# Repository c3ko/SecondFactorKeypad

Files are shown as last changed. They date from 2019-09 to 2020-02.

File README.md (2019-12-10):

# Build Instructions for Second Factor Keypad

## Table of Contents
1. [Introduction](#introduction)
2. [Bill of Materials](#bill-of-materials)
3. [Arduino IDE Configuration](#arduino-ide-configuration)
4. [Soldering and Assembly](#soldering-and-assembly)
5. [Serial Connection](#serial-connection)
6. [Power Up](#power-up)
7. [Testing](#testing)

### Introduction
The 12-Button Matrix Keypad uses a matrix of switches to track which column and row a pressed button is in. The development platform used to read the column/row outputs and drive the state for the lights and buzzer is the Nucleo L432KC. It comes equipped with an onboard ST-LINK v2 and is Arduino IDE compatible.

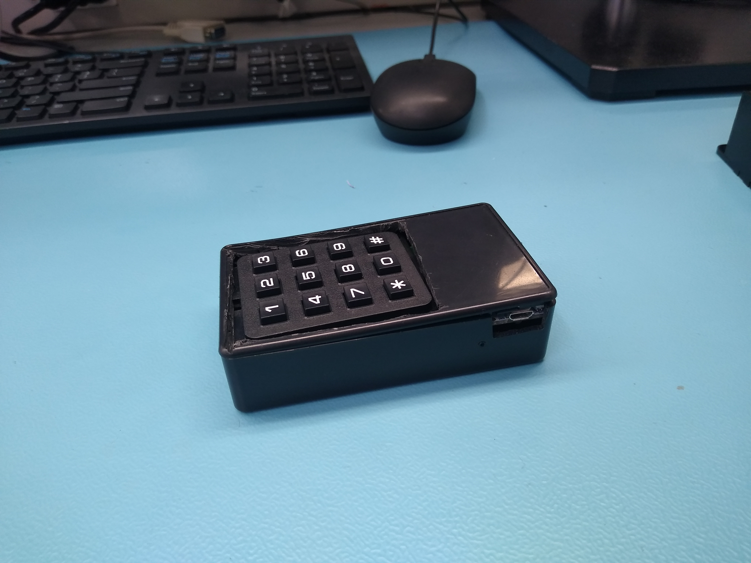
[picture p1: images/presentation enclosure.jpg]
Presentation enclosure


### Bill of Materials
(All Prices pre-tax and in CAD)

*  Nucleo L432KC STM32 Development Board - $15.176
*  COM-14662 12-Button Matrix Keypad - $6.87
*  Red LED - $0.86
*  Green LED - $0.83
*  Piezzo Speaker - $1.04

### Arduino IDE Configuration && installing Source Code
1) The Arduino IDE can be downloaded for free from https://www.arduino.cc/en/main/software and is available for Windows, Mac OS X and Linux.
2) Open Arduino IDE and click Files and then preference.
3) Add the stm32duino board manager repository by entering 'https://raw.githubusercontent.com/stm32duino/BoardManagerFiles/master/STM32/package_stm_index.json' in to 'Additional Boards Manager URLs' and click OK.
4) Plug the micro usb from the Nucleo in to the computer.
5) Click on Tools > Board > Boards Manager and install STM32 Core from the list.
6) Click Tools > Board and select Nucleo-32 and then click Tools > Board Part Number and select Nucleo L432KC.
6) Click Tool > Port and select the port the board is connected to.
7) Install the Keypad.h library by downloading keypad.zip from https://playground.arduino.cc/Code/Keypad/ and install it by clicking Sketch > Include Library > ADD .zip file and select keypad.zip file you downloaded.
7) Download/Copy the source code from https://github.com/c3ko/SecondFactorKeypad/blob/master/software/blink_example1.ino
8) Click Sketch > Upload and then Tools > Serial Monitor to see serial output. Make sure Tools > 
Upload Method is set to STM32CubeProgrammer(SWD).

### Soldering and Assembly
Use the following image as guide for correct position of board on to sockets:

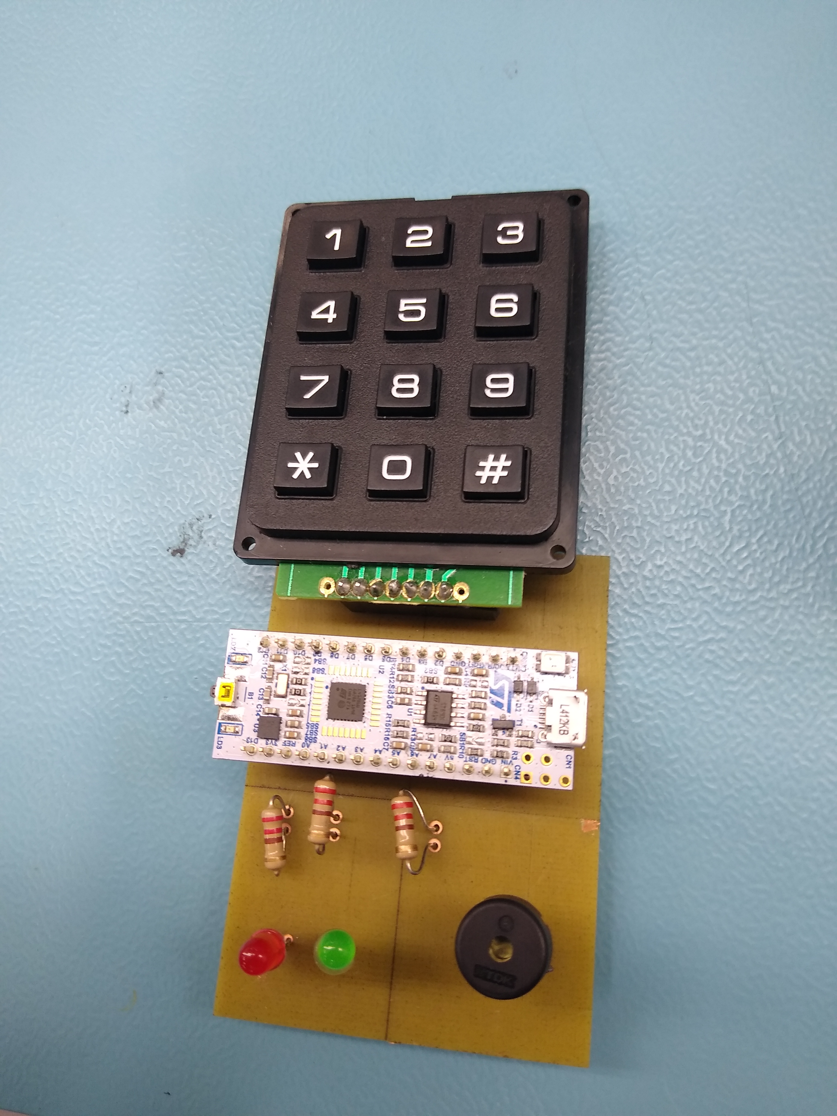
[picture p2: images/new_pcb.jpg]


The PCB Gerber files used for printing the board can be found at https://github.com/c3ko/SecondFactorKeypad/blob/master/mechanical/MohamedKore_SecondFactorKeypadV3.zip
##### Keypad Pins
* Solder Pins on to the Keypad.

#### PCB Pins

* Solder 7-pin single-line header socket on to board
* Solder 2 15-pin single line header sockets on to board
* Solder 3 330 ohm Resistors on to board at output pins for D10, D11, D12

* Solder Piezzo speaker and LED in to their positions based on pCB image above
<br/>

#### Enclosure
Enclosure can be produced using laser cutting of Acrylic. File for cutting can be found at:
https://github.com/c3ko/SecondFactorKeypad/blob/master/MohamedKoreBoxCase.cdr

Use a peice of styrofoam or hard plastic cut to 17mm height 53mm width, 53mm  length to be placed under cantilevered keypad as support.

### Power Up
When PCB hand connected components are inside the enclosure. Plug the Nucleo-32 in to computer using micro-USB outlet on side of enclosure.
### Testing

#### Unit Testing

After soldering the pins on to the keypad. Use a multimeter to measure resistance between the corresponding Row/Column pin for each button. The resistance should drop when button is pressed:

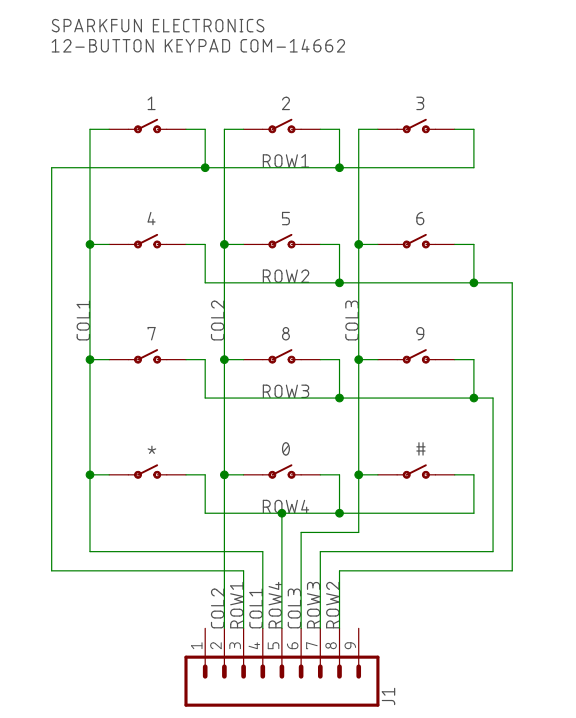
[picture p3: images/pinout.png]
keypad pinout


Test each of the LEDs and the piezzo speaker by setting their digital outputs in the Arduino IDE to high and uploading that sketch to the Nucleo-32.

#### Production Testing

### Reproducability
The project is easily reproducable as all of the components (resistors, keypad, led etc.) are well stocked at major electronic parts suppliers (Digi-key & Mouser). The development environment works on all major operating systems and all of the code has been provided.

### Reference

1.https://circuitdigest.com/microcontroller-projects/getting-started-with-stm32-development-board-stm32f103c8-using-arduino-ide

2. https://playground.arduino.cc/Code/Keypad/

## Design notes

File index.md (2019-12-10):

<h2> December 10, 2019 </h2>

<h3> Project Completion and Build Instructions </h3>

The presentation for this hardware project has been completed and the build instructions for replicating the device is in the README for the project.

<h2>December 3, 2019</h2>

<h3>Update</h3>

<p>
  
  Redesigned PCB to include LED lights and Piezzo speaker to indicate correct/incorrect pin.
  First 3D printing attempt at Idealab failed due to problems with filament. Vertical support on second 3D printed case was too high. Due to time restriction opted for a acrylic Case instead. This has added advantage of making LEDs easily visible withing creating holes for them in the case. Unfortunately didn't communicate need for clear acrylic case, will be sending for a clear top case this week. However, for the presentation I purchased an enclosure that fit my project from Amazon and milled holes using a Dremel handtool and circular saw.

Case used during presentation with old PCB:

Presentation enclosure

Updated PCB:

 Updated PCB
</p>

Failed 3D printed case:

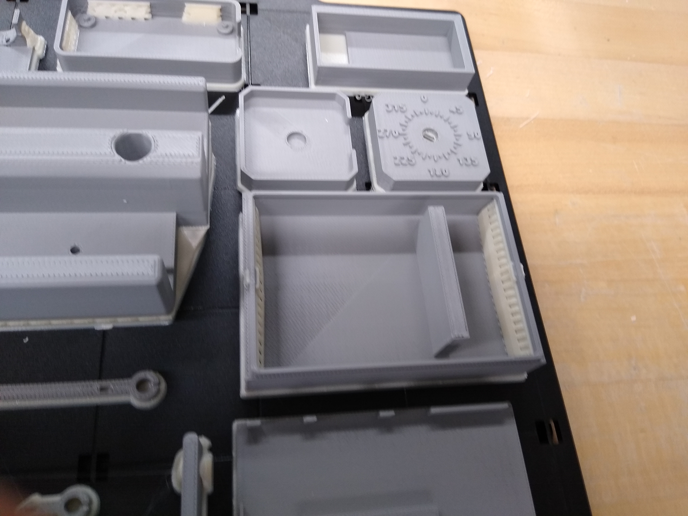
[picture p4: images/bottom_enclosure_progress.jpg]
3d case bottom


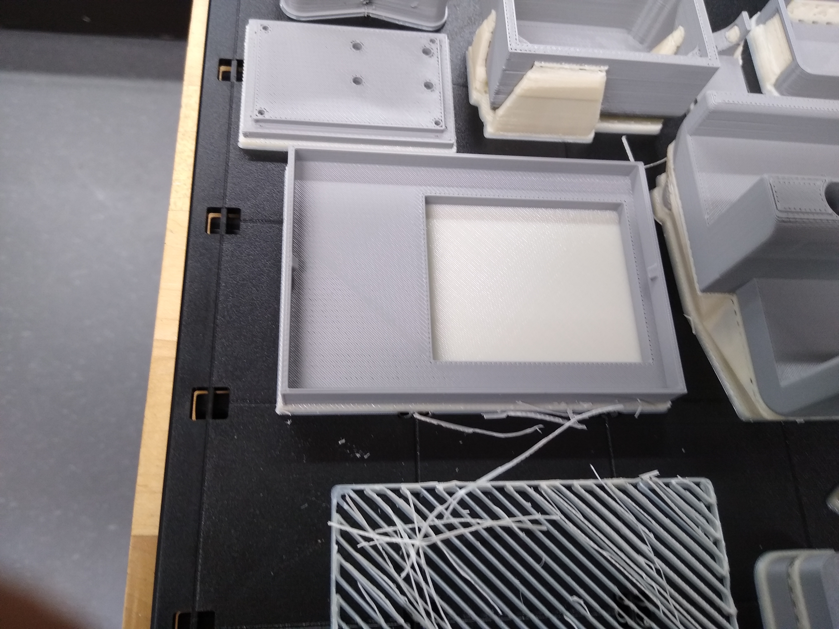
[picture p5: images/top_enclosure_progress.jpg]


<h2>November 26, 2019</h2>

<h3>Presentation Handed In</h3>

<p>
Presentation slides have been completed and can be found under the <a href="documentation/CENG317Presentation.pptx">documentation folder</a>
</p>

<h2>November 19, 2019</h2>

<h3>Enclosure Progress</h3>

<p>
The snap-fit enclosure case for the keypad will have a support cross-section for the keypad to rest on as its current cantilevered position will damage the sockets/pins when pressure is applied to the buttons.
</p>

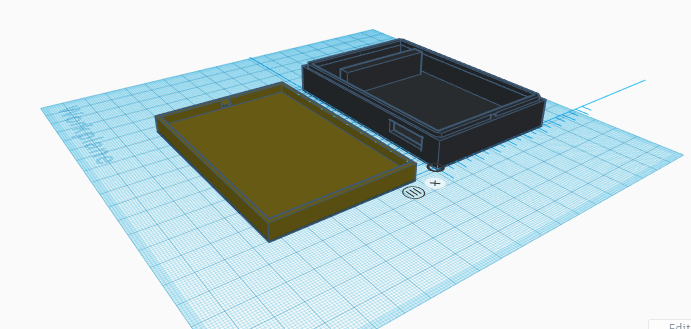
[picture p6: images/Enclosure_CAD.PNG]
keypad enclosure


The files can be found at:

<a href="mechanical/KeyPadEnclosure_bottom.stl">Bottom part of Enclosure STL</a>

<a href="mechanical/KeyPadEnclosure_top.stl">Top part of Enclosure STL</a>

Update: As of November 26, 2019. The enclosure has finished printing but is currently in solution to remove the support material. The tentative date for completion is November 27, 2019.

bottom enclosure progress picture
top enclosure progress picture

<h2>November 11, 2019</h2>

<h3>PCB Powered On</h3>
The 12-Button Keypad uses a grid with switches were connections are closed and a lower resistance allows 5V to pass through. This method for reading key presses doesn't require seperate pins for power and ground so powering up this PCB is as simple as plugging in the the input pins into the socket on the PCB connecting it to the inputs A0-A8 on the Nucleo-32.

keypad pinout

As the images below show. The PCB is powered on and is communicating key presses serially to a terminal:
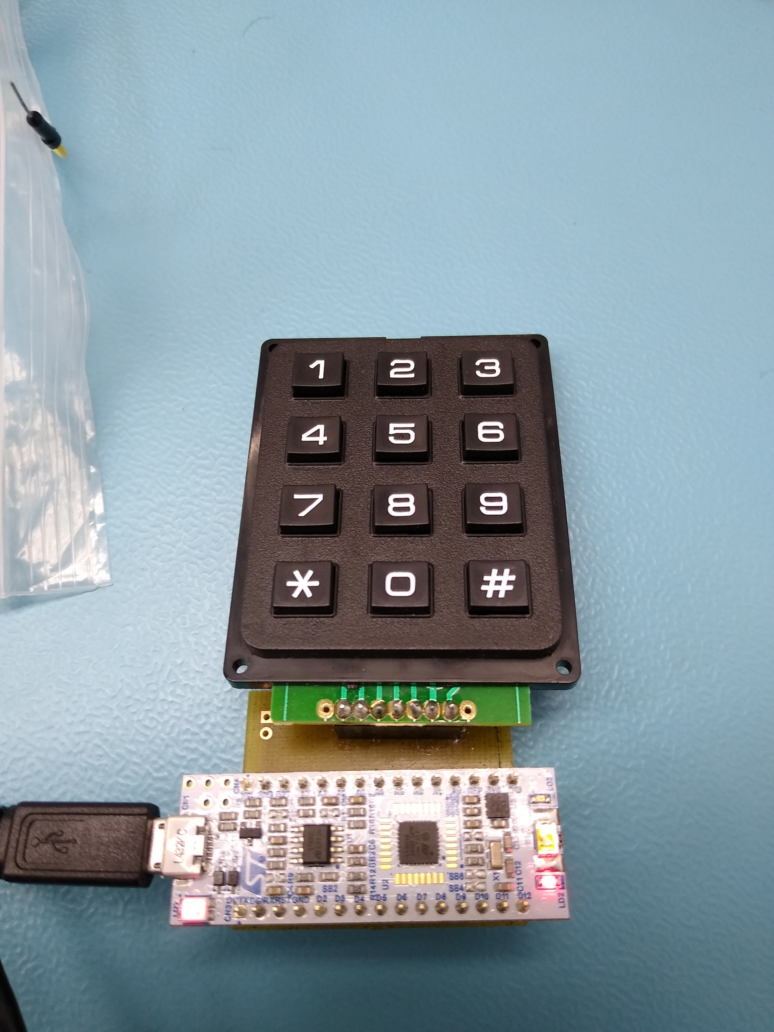
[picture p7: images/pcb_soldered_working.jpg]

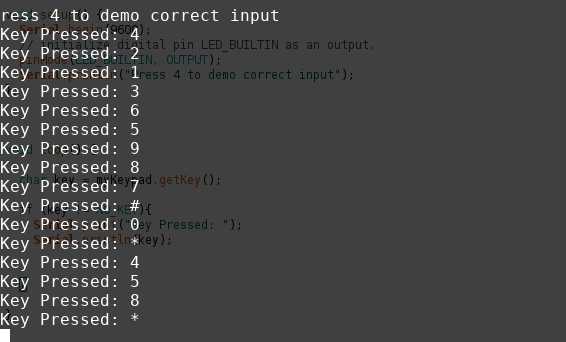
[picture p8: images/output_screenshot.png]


<h2>November 5, 2019</h2>

<h3>PCB Soldered </h3>

<p>The first soldering of headers on the PCB was done on the wrong side of the board. I managed to desolder the headers and solder them back on the component side of the board. There is continuity between the headers and the development board and keypad work as they did on the breadboard: </p>

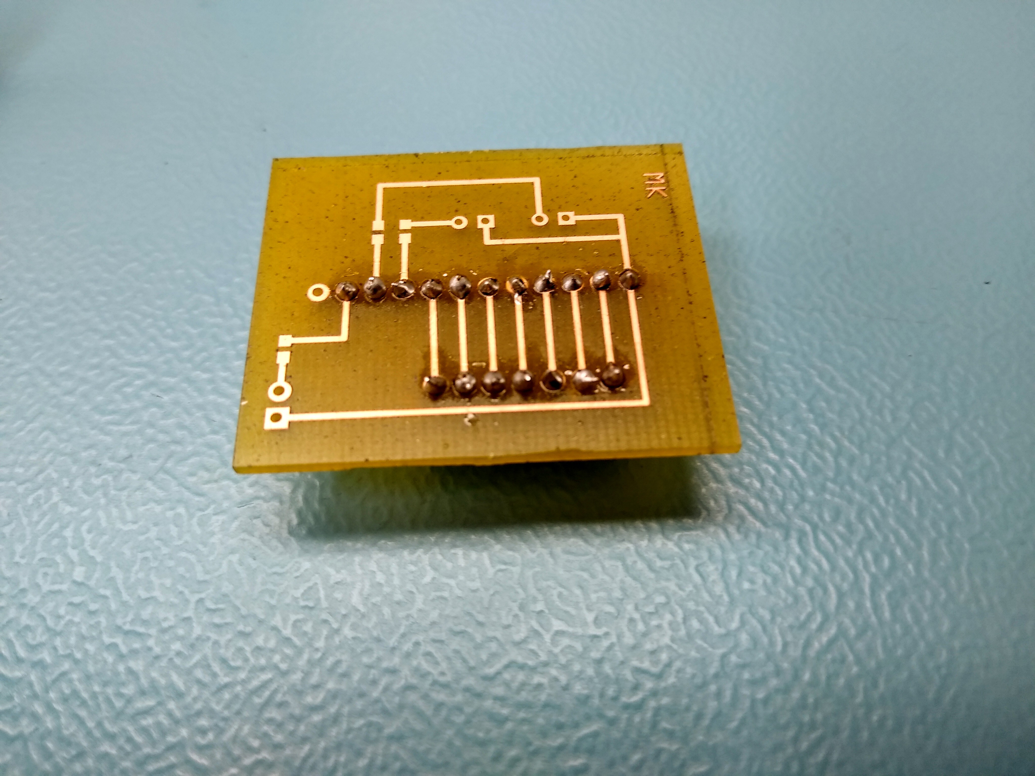
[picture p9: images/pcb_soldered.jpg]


While the original PCB was designed with LED's and a Piezzo Buzzer in mind, I've decided to forego them as their functionality (notifiying a user of a correct or incorrect input) can be more easily implmented using Raspberry Pi which will be connected using the USB port on the Nucleo-32. 

Besides that, the project is on schedule and no new parts were required.

<h2>October 29, 2019</h2>

<h3>Update </h3>
It turns out that when I had straightened the header on the keypad, the contact between the solder and the copper surface flexed, taking the copper surface pads off the keypad with the exception of pins 8 and 4, which are for row 2 and column 1 respectively. This is likely why 4 was the only button working on the keypad. 

<p>I ordered and received another keypad:</p>

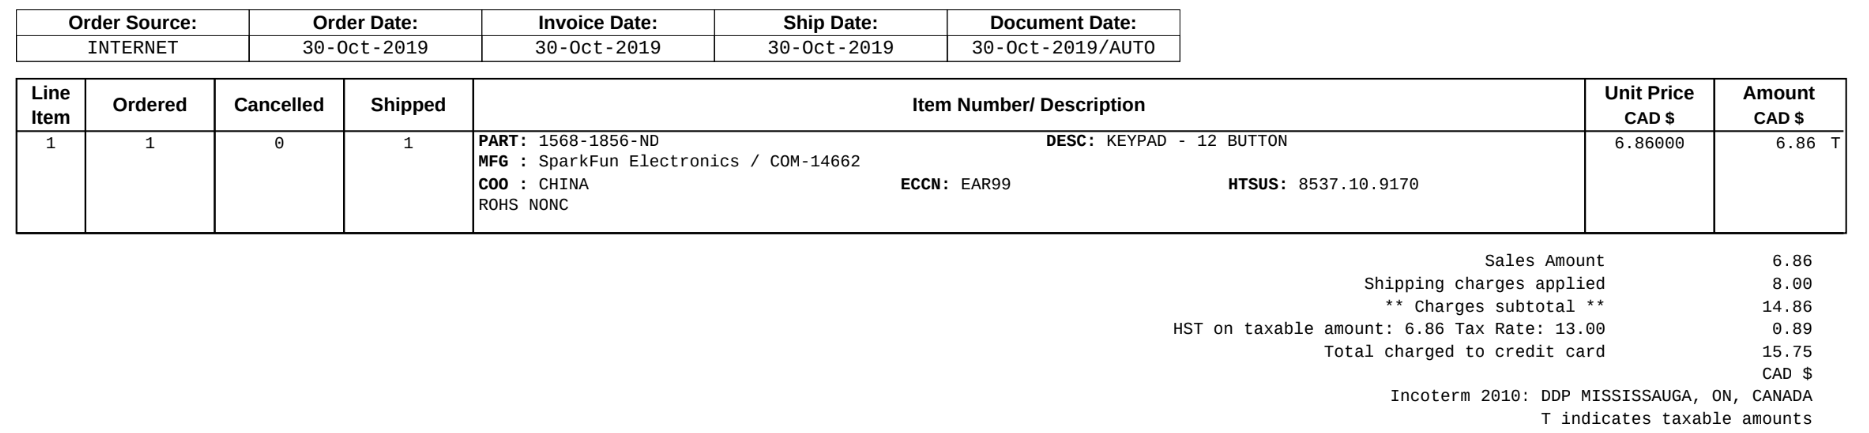
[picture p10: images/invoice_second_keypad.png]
keypad pcb


This added an additional $15.75 to the budget (includeing shipping).

<p>The new keypad works perfectly. Screenshots of the output and the code used. </p>

keypad pcb
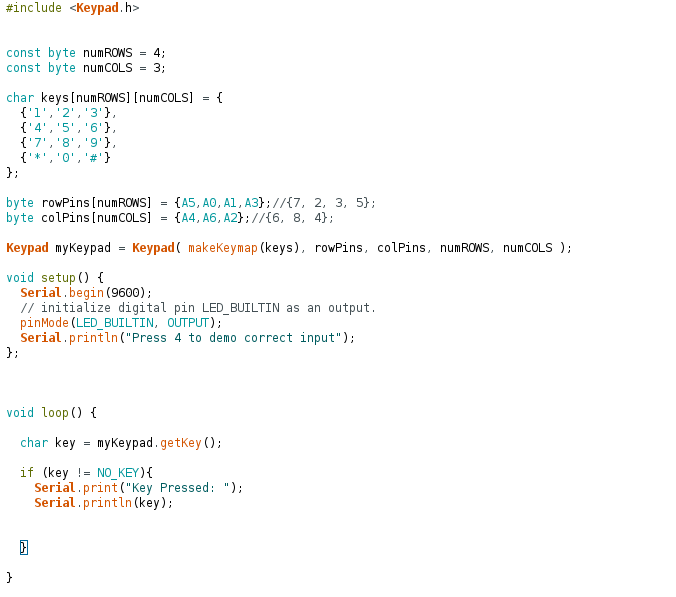
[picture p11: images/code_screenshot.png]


The code was sourced from a tutorial example at: <a href="http://robojax.com/learn/arduino/?vid=robojax-keypad-4x3">Robojax 4x3 Keypad Example</a>

My code file can be found at: <a href="software/blink_example1.ino">sotfware/blink_example1.ino</a>

<h3>Breadboard Milestone</h3>
Soldered Header pins on to the Keypad. Red light and three buzzes when when entered number doesn't match hardcoded value. Green light and single alarm when correct.

The Keypad appears to be defective. When running the only number that produces an output is 4. Also, when measuring the resistance between the corresponding col and row pins for each number, there is an open circuit with the exception of 4.

The rest of the components on the breadboard are working fine and I've ordered another keypad from Digikey to replace the defective one.
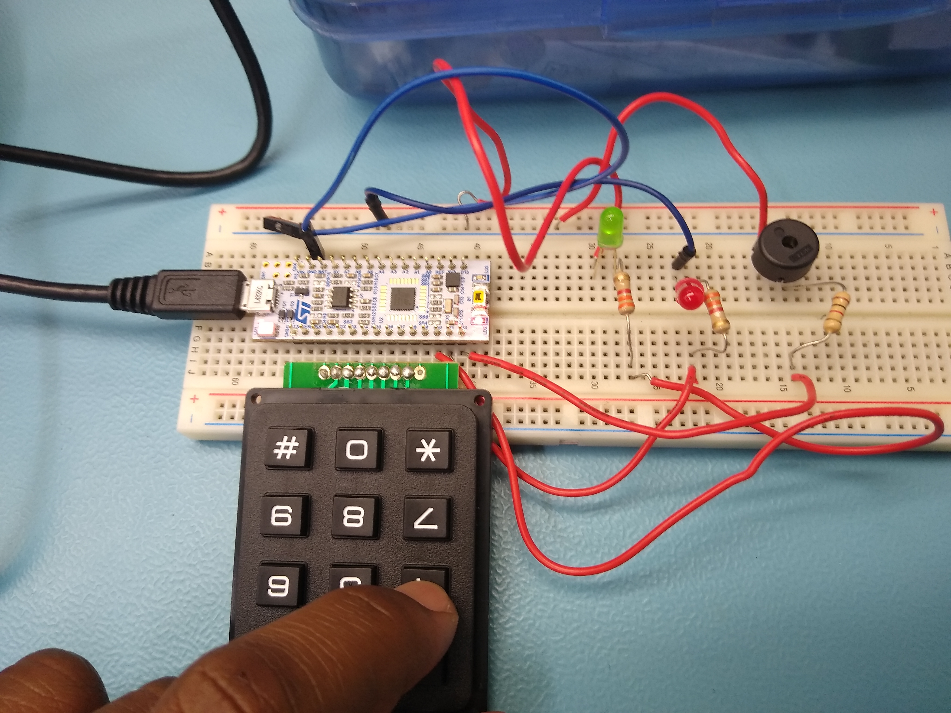
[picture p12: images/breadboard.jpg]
breadboard


<h2>October 15, 2019</h2>

<h3>Updated Fritzing Designs</h3>
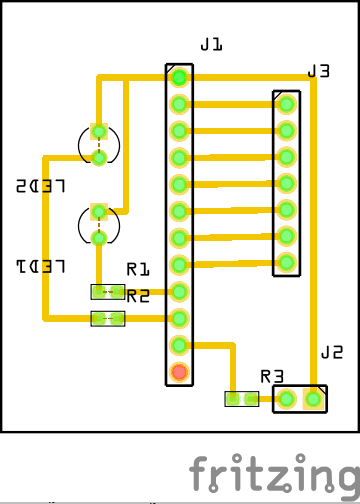
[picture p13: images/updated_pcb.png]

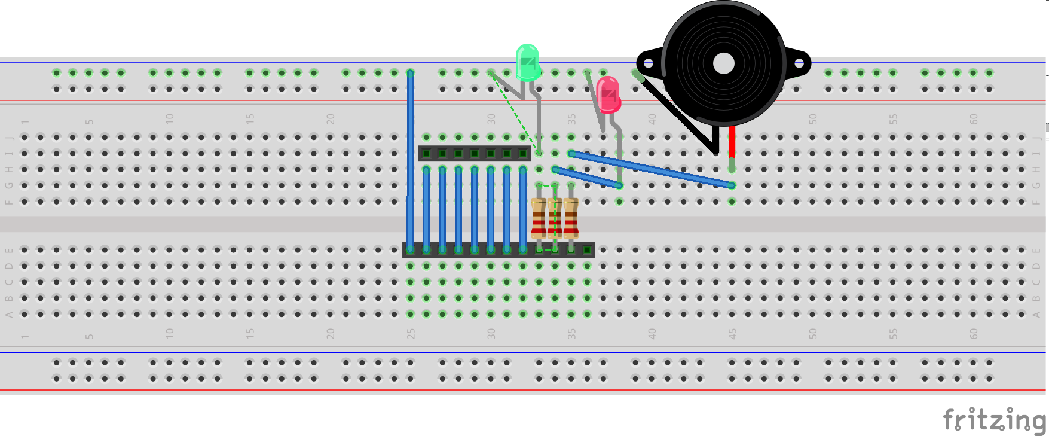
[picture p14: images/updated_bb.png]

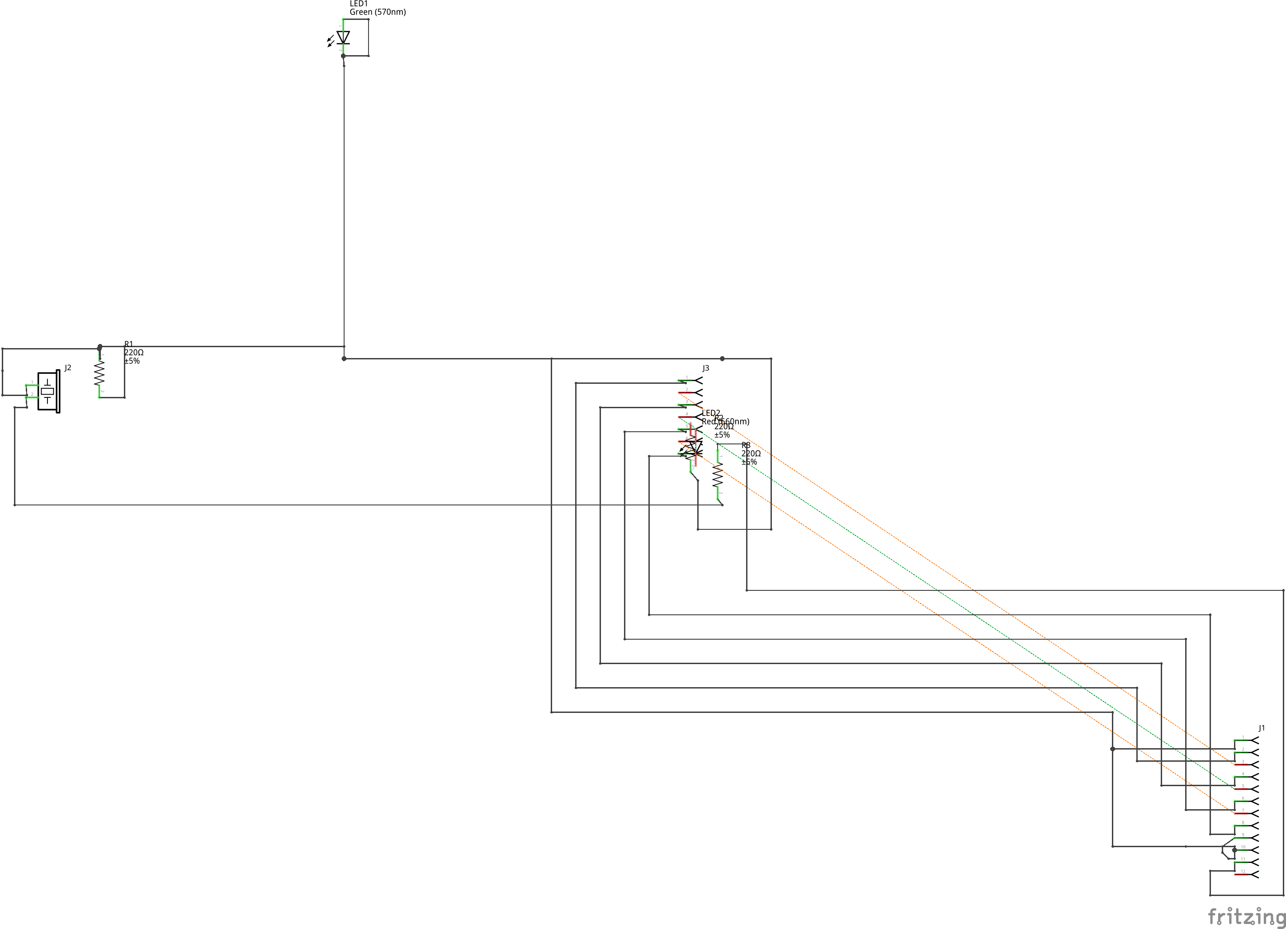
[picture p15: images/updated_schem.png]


<h3>Fritzing Designs</h3>
<p color="red">These designs are temporary as I'm using a Nucleo-32 instead of the STM32 blue pill board. I'm in the process of making designs with custom header pins based on the Nucleo L432KC in Fritzing</p>
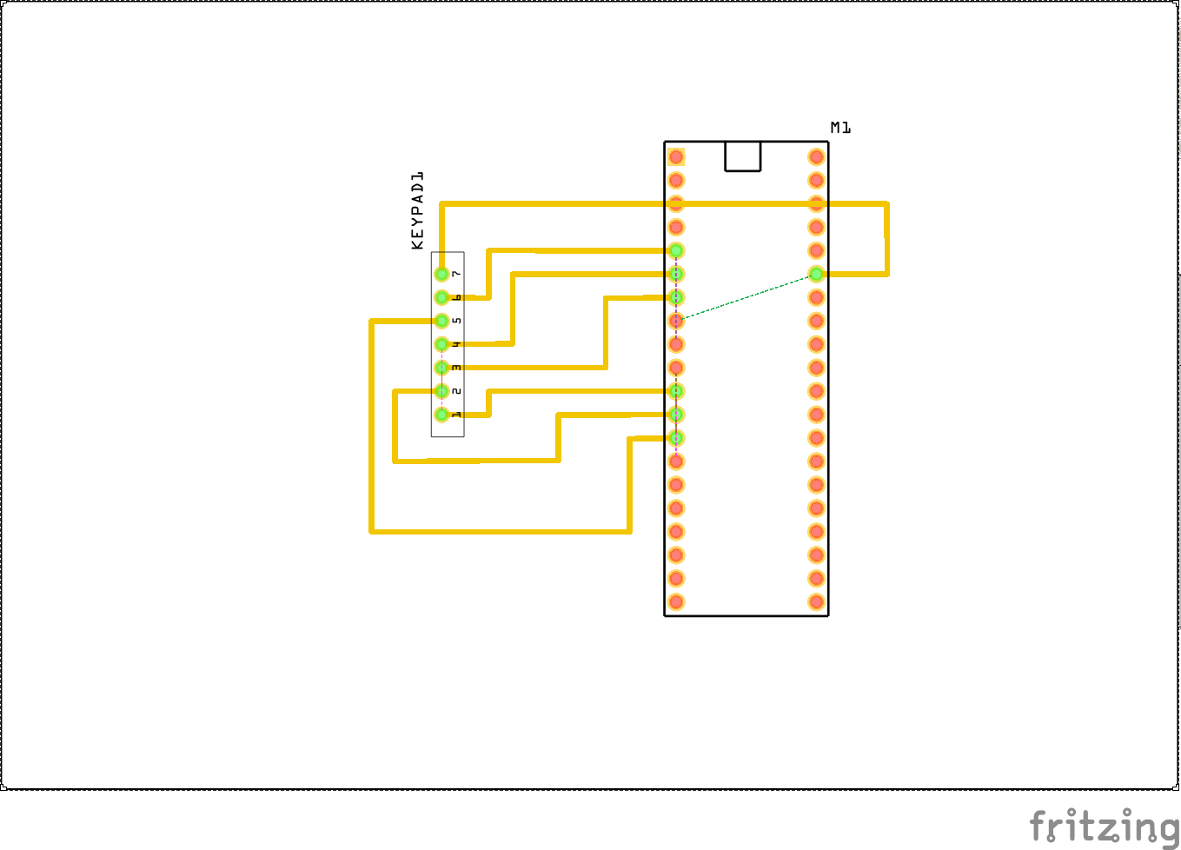
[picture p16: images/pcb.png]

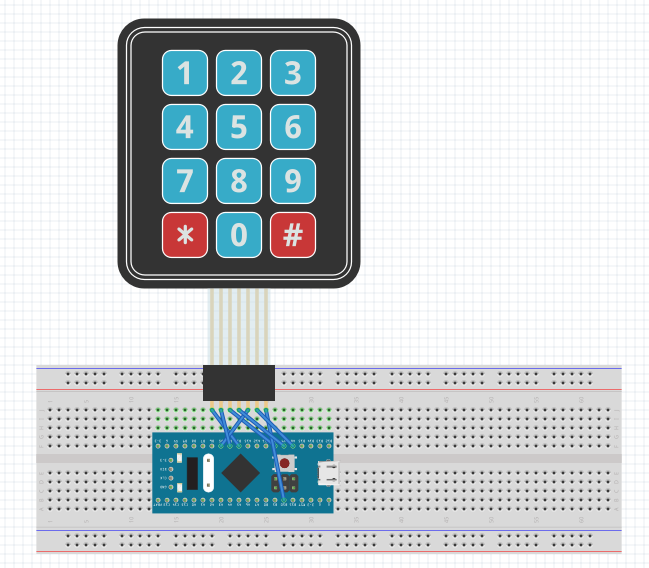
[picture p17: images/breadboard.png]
keypad breadboard

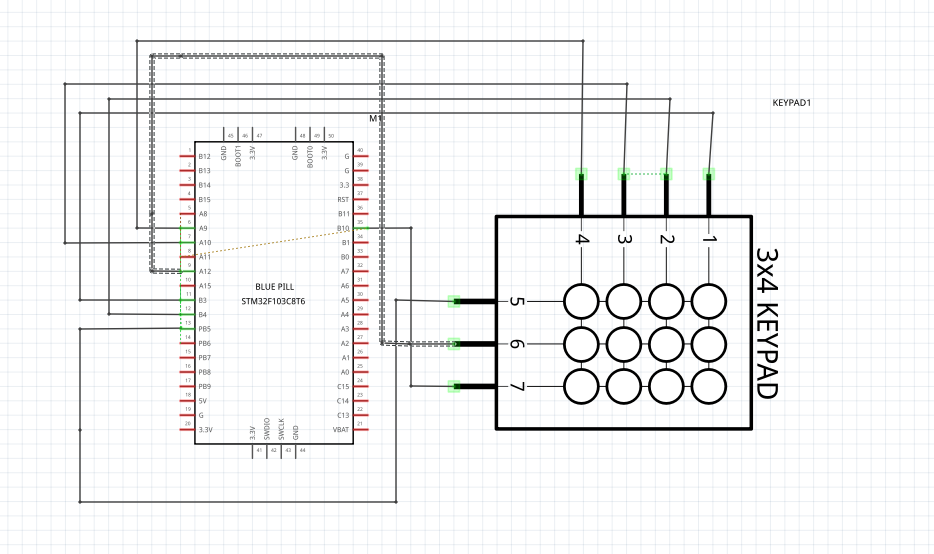
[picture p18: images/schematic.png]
keypad schematic

<h2>October 8, 2019</h2>
<h3>Proof of Acquisition</h3>
<p>All parts arrived together on Tuesday, October 1, 2019</p>
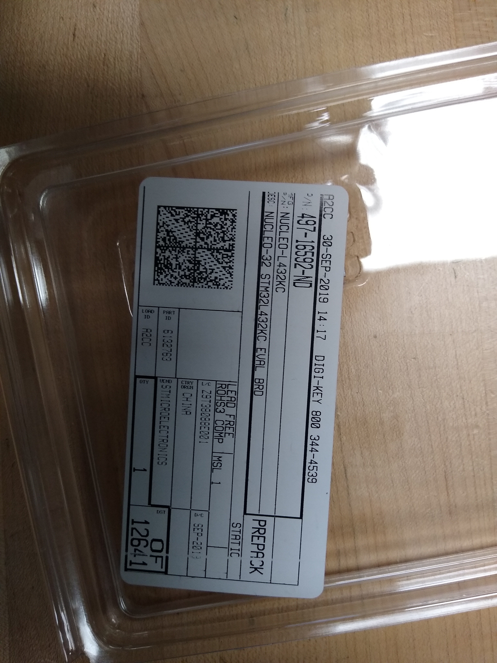
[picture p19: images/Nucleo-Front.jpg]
Nucleo

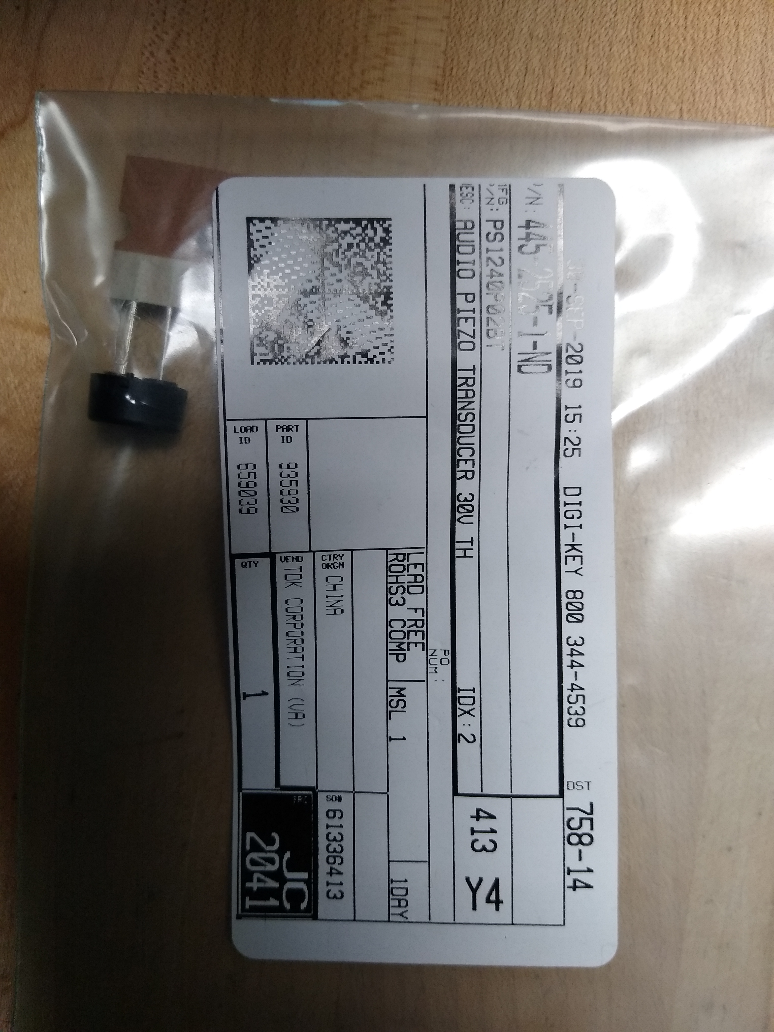
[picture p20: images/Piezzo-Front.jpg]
Piezo

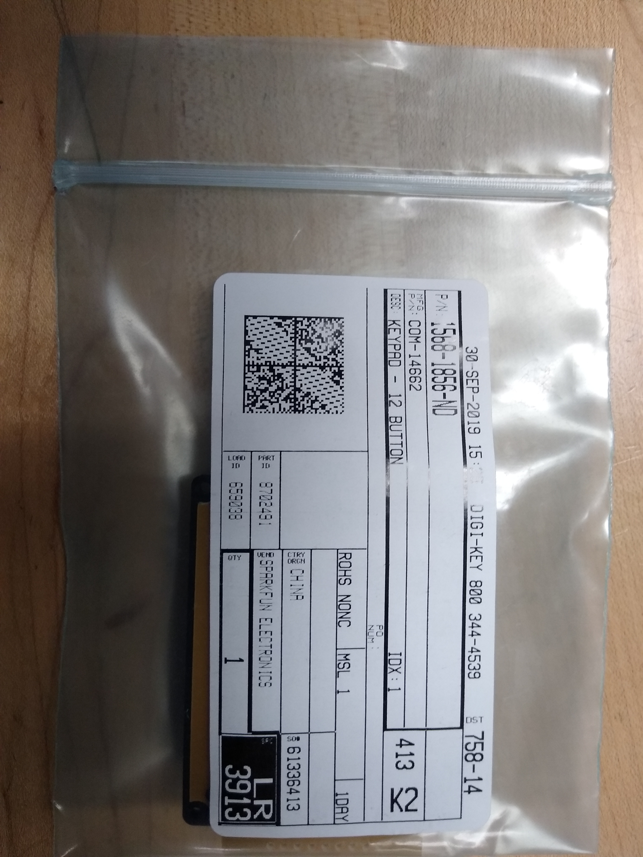
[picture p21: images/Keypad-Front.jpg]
Keypad

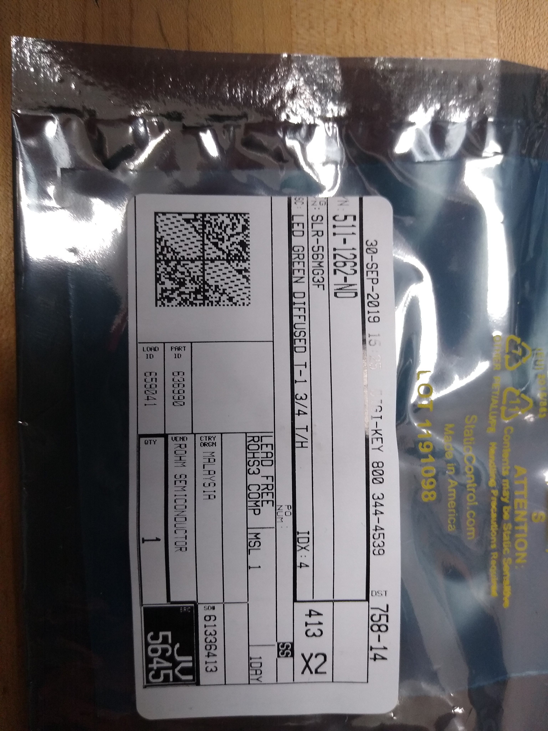
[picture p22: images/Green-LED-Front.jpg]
Green LED

RED LED
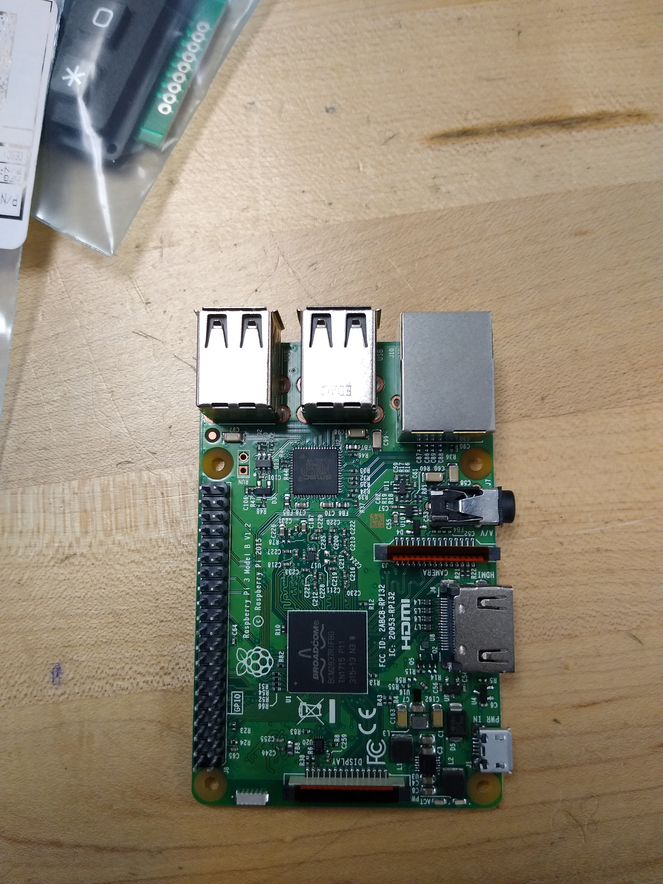
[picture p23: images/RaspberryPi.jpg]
Raspberry Pi


<p>The Green and Red LED lights are for prototyping on the breadboard. The Nucleo L432KC has a built in debugger and is compatible with Arduino IDE. This week I'll setup the Arduino IDE environment to work with the board. </p>
<h2>October 1, 2019</h2>
<p>The parts have been ordered and should arrive by October 1st.</p>
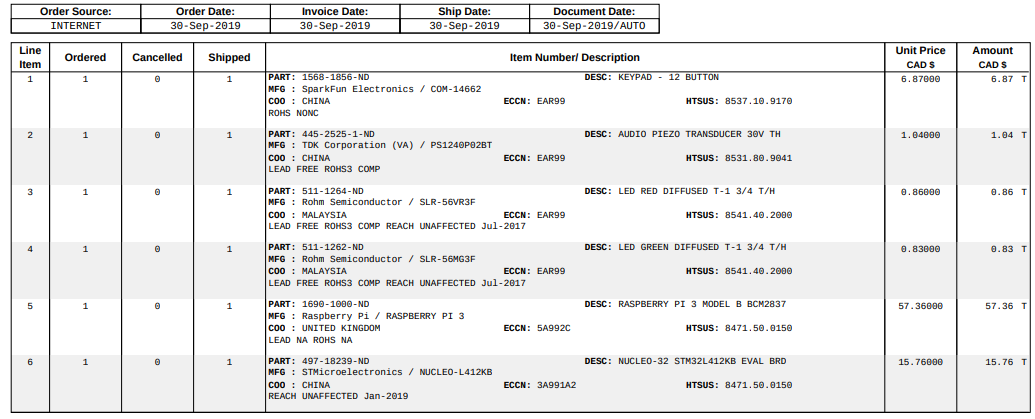
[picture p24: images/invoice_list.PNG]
invoice list

<p>The total for the budget has changed as I've decided to use the NUCLEO-L412KB using mbed. This was due to the order for the blue pill being cancelled and prime shipping was no longer available.</p>
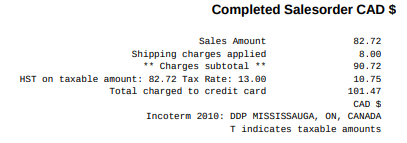
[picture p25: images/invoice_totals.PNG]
invoice totals


<h2>September 24th, 2019</h2>
<h3>Budget Summary</h3>
<p>Sub-Total: $86.84 CAD</p>
<p>Taxes: $11.29 CAD</p>
<p>Shipping: $8.00 CAD</p>
<p>Total: $106.13</p>

Full Budget breakdown can be found Here:
<a href="documentation/Budget.xlsx">Budget Spreadsheet</a>

<h2>September 17th, 2019</h2>
<p>Gantt Chart and Schedule Overview:<p>
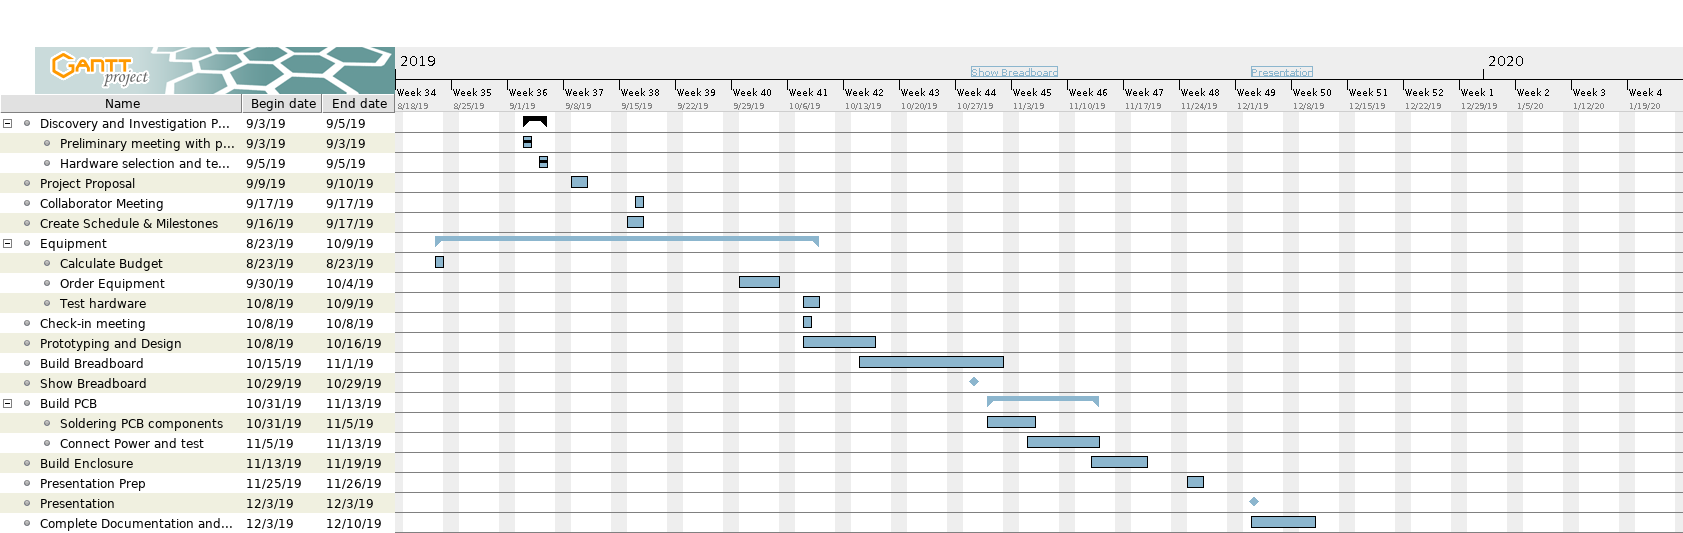
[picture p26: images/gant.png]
gantt chart


<h2>September 10th, 2019</h2>
<p>For my hardware project, I've decided to implement a two-factor authentication system using a Keypad.<p>
This project will require at minimum:
<ul>
  <li>COM-14662 12-Button Keypad</li>
  <li>STM32f103c8t6 board</li>
  <li>LED lights</li>
  <li>Speaker</li>
</ul>

<h2>September 9th, 2019</h2>
<p>Repository Created!</p>

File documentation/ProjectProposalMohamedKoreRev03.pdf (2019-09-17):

43718

Proposal for the development of PartsCrib Management System
Prepared by Mohamed Kore, Gurkuran Padda, Ricky Ramnath

Computer Engineering Technology Students

https://github.com/c3ko/SecondFactorKeypad

Executive Summary
As a student in the Computer Engineering Technology program, I will be integrating the knowledge and skills I have learned from our program into this Internet of Things themed capstone project. This proposal requests the approval to build the hardware portion that will connect to a database as well as to a mobile device application. The internet connected hardware will include a custom PCB with the following sensors and actuators KeyPad, RFID reader, GPS sensor. The database will store key-Value Pairs consisting of student number and 5 pin number.. The mobile device functionality will include the ability for students to check which items are available and to make a request to borrow them. and will be further detailed in the mobile application proposal. I will be collaborating with the following company/department Humber College Parts Crib. In the winter semester I plan to form a group with the following students, who are also building similar hardware this term and working on the mobile application with me Mohamed Kore, Gurkuran Padda, Ricky Ramnath. The hardware will be completed in CENG 317 Hardware Production Techniques independently and the application will be completed in CENG 319 Software Project. These will be integrated together in the subsequent term in CENG 355 Computer Systems Project as a member of a 2 or 3 student group.

Background
The problem solved by this project is Problem: The slow and tedious system in place for lending electronics from the parts crib to students. The process requires the use of large amounts of paper each day and it is difficult for the parts crib to track important trends such as which items are being requested the most at certain times.. A bit of background about this topic is It’s not a rare occurrence for items to missing at the parts crib and the time required to track down which student didn’t return an item is costly. The goal of this project is to implement a system that will allow the parts crib to keep an electronic catalogue of items loaned out to students. Students will be able to use a mobile android-based application to see what items are available and to request them using their student credentials..
Existing products on the market include [1]. I have searched for prior art via Humber’s IEEE subscription selecting “My Subscribed Content”[2] and have found and read [3] which provides insight into similar efforts. In the Computer Engineering Technology program we have learned about the following topics from the respective relevant courses:
- Java Docs from CENG 212 Programming Techniques In Java,
- Construction of circuits from CENG 215 Digital And Interfacing Systems,
- Rapid application development and Gantt charts from CENG 216 Intro to Software Engineering,
- Micro computing from CENG 252 Embedded Systems,
- SQL from CENG 254 Database With Java,
- Web access of databases from CENG 256 Internet Scripting; and,
- Wireless protocols such as 802.11 from TECH152 Telecom Networks.
This knowledge and skill set will enable me to build the subsystems and integrate them together as my capstone project.

Page 2

Methodology
This proposal is assigned in the first week of class and is due at the beginning of class in the second week of the fall semester. My coursework will focus on the first two of the 3 phases of this project:
Phase 1 Hardware build.
Phase 2 System integration.
Phase 3 Demonstration to future employers.

Phase 1 Hardware build
The hardware build will be completed in the fall term. It will fit within the CENG Project maximum dimensions of 12 13/16" x 6" x 2 7/8" (32.5cm x 15.25cm x 7.25cm) which represents the space below the tray in the parts kit. The highest AC voltage that will be used is 16Vrms from a wall adaptor from which +/-15V or as high as 45 VDC can be obtained. Maximum power consumption will be 20 Watts.

Phase 2 System integration
The system integration will be completed in the fall term.

Phase 3 Demonstration to future employers
This project will showcase the knowledge and skills that I have learned to potential employers.
The brief description below provides rough effort and non-labour estimates respectively for each phase. A Gantt chart will be added by week 3 to provide more project schedule details and a more complete budget will be added by week 4. It is important to start tasks as soon as possible to be able to meet deadlines.
COM-14662 12-Button KeyPad, RC522 RFID reader, stm32f103c8t6, GPS sensor, Raspberry Pi

Concluding remarks
This proposal presents a plan for providing an IoT solution for Students will use a RFID reader to scan a tag placed on their card along. They will then input a randomly-generated 4 digit number generated using a phone app. The app will only work when used on the Humber network. Thus, there is no requirement to verify student identity manually at the part crib as the code was generated on password-protected phone (mandated by my-wifi@humber).. This is an opportunity to integrate the knowledge and skills developed in our program to create a collaborative IoT capstone project demonstrating my ability to learn how to support projects such as the initiative described by [3]. I request approval of this project.

References
[1] (2018, November 16). Modis Lock. Retrieved from https://modis.io/modis-lock/
[2] Institute of Electrical and Electronics Engineers. (2015, August 28). IEEE Xplore Digital Library [Online]. Available: https://ieeexplore.ieee.org/search/advsearch.jsp
[3] 0

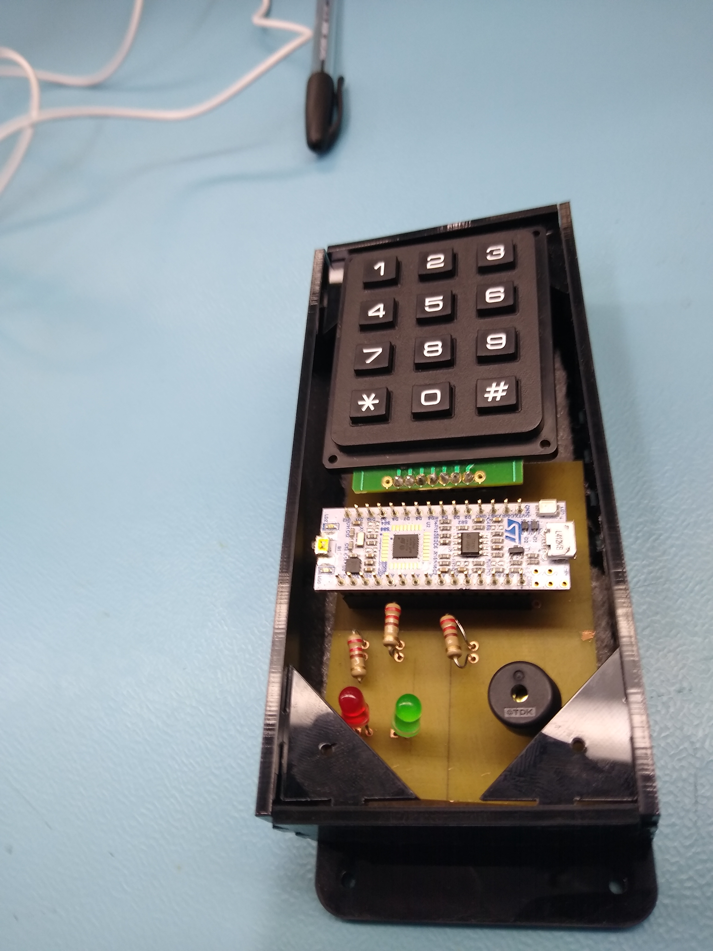
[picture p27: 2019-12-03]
images/acrylic_enclosure.jpg

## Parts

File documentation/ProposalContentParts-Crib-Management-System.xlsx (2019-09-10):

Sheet: DataEntry
Submission Date | 2019-09-10
Project Name | PartsCrib Management System
Student Names | Mohamed Kore, Gurkuran Padda
Project repository | https://github.com/c3ko/SecondFactorKeypad
SensorsEffectors choices | KeyPad, RFID reader, GPS sensor
The database will store | key-Value Pairs consisting of student number and 5 pin number.
The mobile device functionality will include | the ability for students to check which items are available and to make a request to borrow them.
I will be collaborating with the following company/department | Humber College Parts Crib
My group in the winter semester will include | Mohamed Kore, Gurkuran Padda, Ricky Ramnath
50 word problem statement | Problem: The slow and tedious system in place for lending electronics from the parts crib to students. The process requires the use of large amounts of paper each day and it is difficult for the parts crib to track important trends such as which items are being requested the most at certain times.
100 words of background | It’s not a rare occurrence for items to missing at the parts crib and the time required to track down which student didn’t return an item is costly. The goal of this project is to implement a system that will allow the parts crib to keep an electronic catalogue of items loaned out to students. Students will be able to use a mobile android-based application to see what items are available and to request them using their student credentials.
Current product APA citation | (2018, November 16). Modis Lock. Retrieved from https://modis.io/modis-lock/
Existing research IEEE paper APA citation
Brief description of planned purchases | COM-14662 12-Button KeyPad, RC522 RFID reader, stm32f103c8t6, GPS sensor, Raspberry Pi
Solution description | Students will use a RFID reader to scan a tag placed on their card along. They will then input a randomly-generated 4 digit number generated using a phone app. The app will only work when used on the Humber network. Thus, there is no requirement to verify student identity manually at the part crib as the code was generated on password-protected phone (mandated by my-wifi@humber).

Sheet: DataBase
Submission Date | Project Name | Student Names | Project repository | SensorsEffectors choices | The database will store | The mobile device functionality will include | I will be collaborating with the following company/department | My group in the winter semester will include | 50 word problem statement | 100 words of background | Current product APA citation | Existing research IEEE paper APA citation | Brief description of planned purchases | Solution description
43718 | PartsCrib Management System | Mohamed Kore, Gurkuran Padda | https://github.com/c3ko/SecondFactorKeypad | KeyPad, RFID reader, GPS sensor | key-Value Pairs consisting of student number and 5 pin number. | the ability for students to check which items are available and to make a request to borrow them. | Humber College Parts Crib | Mohamed Kore, Gurkuran Padda, Ricky Ramnath | Problem: The slow and tedious system in place for lending electronics from the parts crib to students. The process requires the use of large amounts of paper each day and it is difficult for the parts crib to track important trends such as which items are being requested the most at certain times. | It’s not a rare occurrence for items to missing at the parts crib and the time required to track down which student didn’t return an item is costly. The goal of this project is to implement a system that will allow the parts crib to keep an electronic catalogue of items loaned out to students. Students will be able to use a mobile android-based application to see what items are available and to request them using their student credentials. | (2018, November 16). Modis Lock. Retrieved from https://modis.io/modis-lock/ | 0 | COM-14662 12-Button KeyPad, RC522 RFID reader, stm32f103c8t6, GPS sensor, Raspberry Pi | Students will use a RFID reader to scan a tag placed on their card along. They will then input a randomly-generated 4 digit number generated using a phone app. The app will only work when used on the Humber network. Thus, there is no requirement to verify student identity manually at the part crib as the code was generated on password-protected phone (mandated by my-wifi@humber).

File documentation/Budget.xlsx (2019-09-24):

Second Factor Keypad Authentication
Description | Source | Part # | $USD Price | $CAD Price | $USD Total | $CAD Total | Link
SparkFun 12-Button Keypad COM-14662 | Digikey | COM-14662 |  | $6.87 |  |  | https://www.sparkfun.com/products/14193?_ga=2.97662492.2095878335.1537831851-1448490607.1536633859
SparkFun Qwiic HAT for Raspberry Pi | Sparkfun | DEV-14459 |  |  |  |  | https://www.sparkfun.com/products/14459?_ga=2.64157484.2095878335.1537831851-1448490607.1536633859
Qwiic Cable - 500mm | Sparkfun | PRT-14429 |  |  |  |  | https://www.sparkfun.com/products/14429?_ga=2.93074078.2095878335.1537831851-1448490607.1536633859
Tax and Customs |  |  | ??
Shipping and Handling |  |  | ??
 |  |  |  |  | ????
Raspberry Pi 3 Starter Kit | Amazon | N/A | N/A | N/A | N/A | N/A
Humber Parts kit | Bookstore | N/A | N/A | N/A | N/A | N/A
PCB | Prototype Lab | N/A | N/A | N/A | N/A | N/A
Grand Total (using CAD$1=USD$0.77) |  |  |  |  | ????

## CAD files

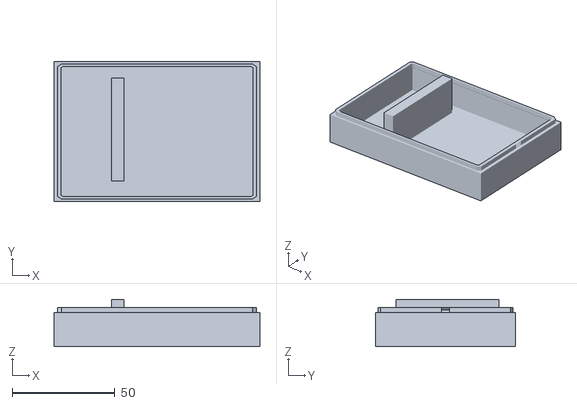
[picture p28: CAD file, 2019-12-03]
mechanical/Mohamed_Kore_Keypad_Bottom.stl
100.0 x 68.0 x 23.0

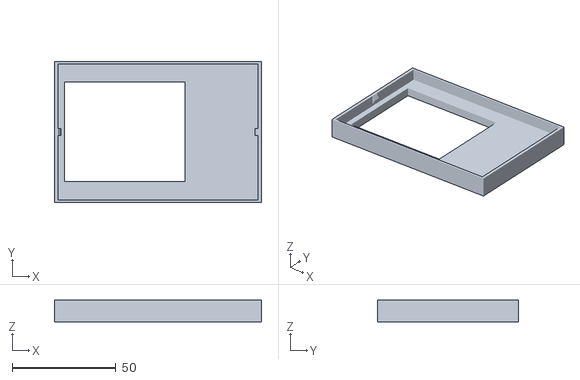
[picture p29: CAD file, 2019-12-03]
mechanical/Mohamed_Kore_Keypad_Top.stl
100.0 x 68.0 x 10.5

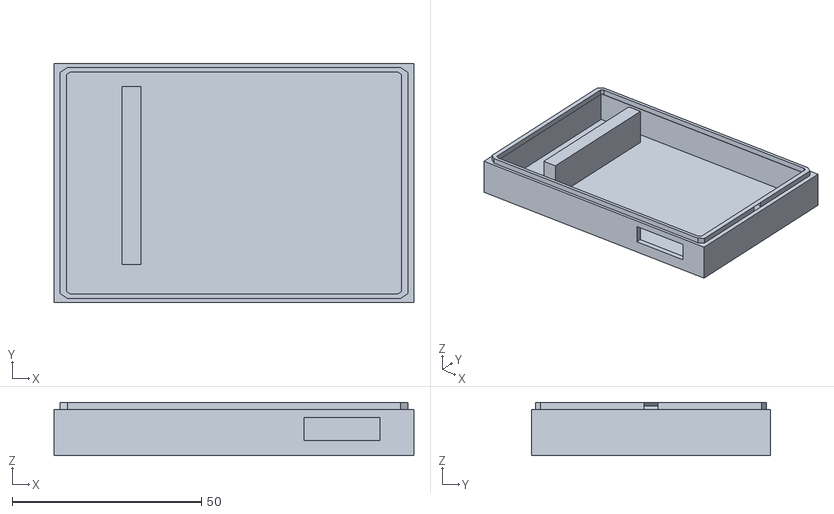
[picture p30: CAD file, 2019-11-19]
mechanical/KeyPadEnclosure_bottom.stl
95.0 x 63.0 x 14.0

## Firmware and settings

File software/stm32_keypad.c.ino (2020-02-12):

#include <Keypad.h>
#include <HardwareSerial.h>

HardwareSerial Serial1(D1,D0);

const byte numROWS = 4;
const byte numCOLS = 3;

char keys[numROWS][numCOLS] = {
  {'1','2','3'},
  {'4','5','6'},
  {'7','8','9'},
  {'*','0','#'}
};

byte rowPins[numROWS] = {A1,A6,A5,A3};//{7, 2, 3, 5};  
byte colPins[numCOLS] = {A2,A0,A4};//{6, 8, 4}; 

Keypad myKeypad = Keypad( makeKeymap(keys), rowPins, colPins, numROWS, numCOLS );

void setup() {
  Serial1.begin(9600);
  // initialize digital pin LED_BUILTIN as an output.
  pinMode(LED_BUILTIN, OUTPUT);
  pinMode(D12, OUTPUT); // Red Light
  pinMode(D11, OUTPUT);
  pinMode(D10, OUTPUT);
  Serial1.println("Press 4 to demo correct input");
};



void loop() {

  char key = myKeypad.getKey();
  
  if (key != NO_KEY){
    Serial1.print("Key Pressed: ");
    Serial1.println(key);

    switch(key){

      case '4':
        digitalWrite(D12, HIGH);
        digitalWrite(D11, HIGH);
        //tone(D10,450);
        digitalWrite(D10, HIGH);
        break;

      case '5':
        digitalWrite(D12, LOW);
        digitalWrite(D11, LOW);
        digitalWrite(D10,LOW);
        //noTone(D10);
        break;
    }

  } 

}

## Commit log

2019-09-10 create directories
    [ProposalContentParts-Crib-Management-System.xlsx]
2019-09-10 proposal file
    [ProposalContentParts-Crib-Management-System.xlsx]
2019-09-24 Added budget
    [Budget.xlsx]
2019-11-05 Arduino source file
2019-11-05 pcb soldered images
2019-11-19 Added enclosure CAD files
    [KeyPadEnclosure_bottom.stl, KeyPadEnclosure_top.stl]
